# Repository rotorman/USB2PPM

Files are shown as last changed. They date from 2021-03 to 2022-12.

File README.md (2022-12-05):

# USB2PPM
Interface to control a remote device (e.g. a drone) from the PC via a radio link.

The USB2PPM circuit gets the signal from PC over USB connection and converts it to Pulse-Position-Modulation (PPM) to be input e.g. over a trainer jack into a remote control transmitter.

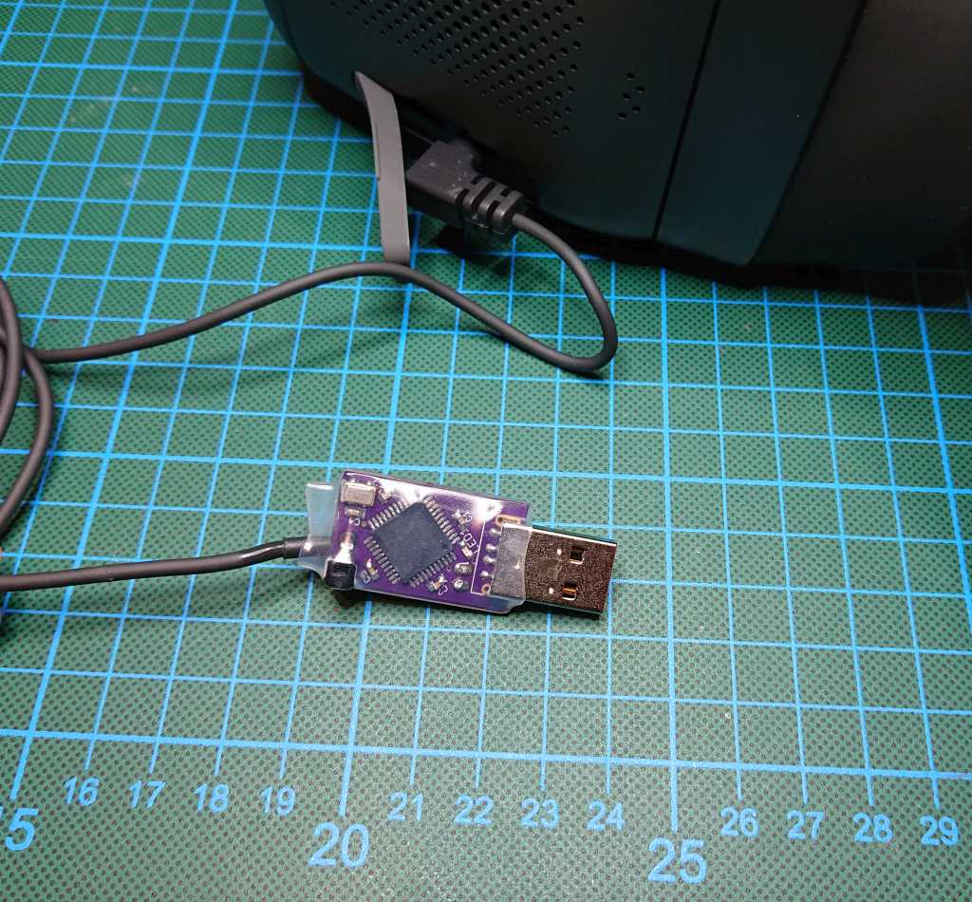
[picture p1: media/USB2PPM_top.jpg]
Top side of the PCB
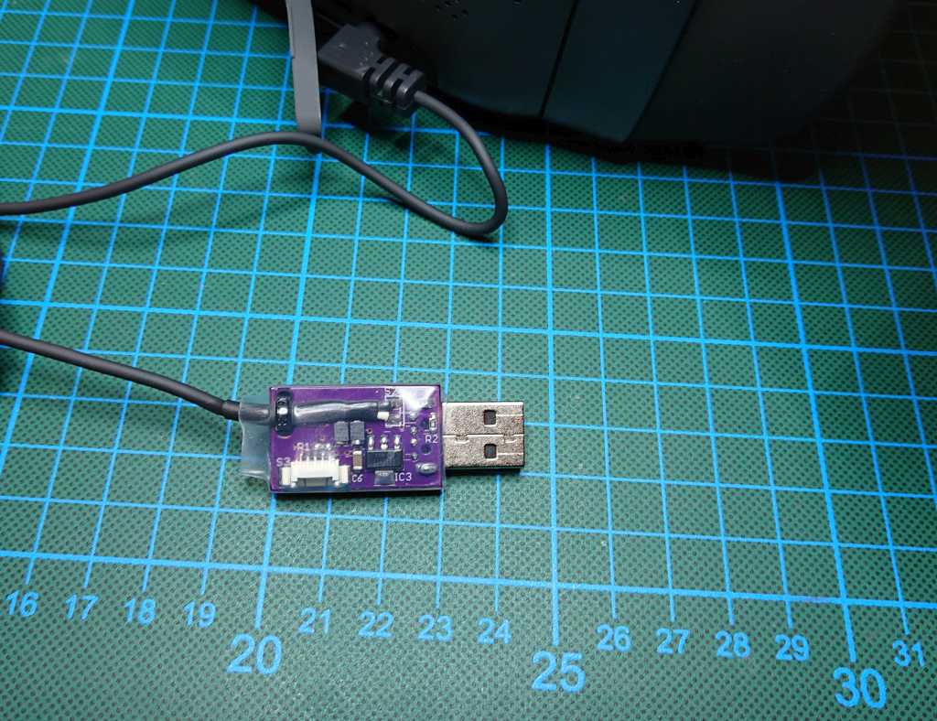
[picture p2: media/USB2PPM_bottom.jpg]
Bottom side of the PCB
 

USB2PPM outputs standard trainer port signal. You will find Eagle schematic & board files, Microchip MPLAB X PIC32 Harmony project (including pre-built firmware HEX) and two Microsoft Visual Studio .NET C# projects (incl. pre-built Windows binary) to control the board.

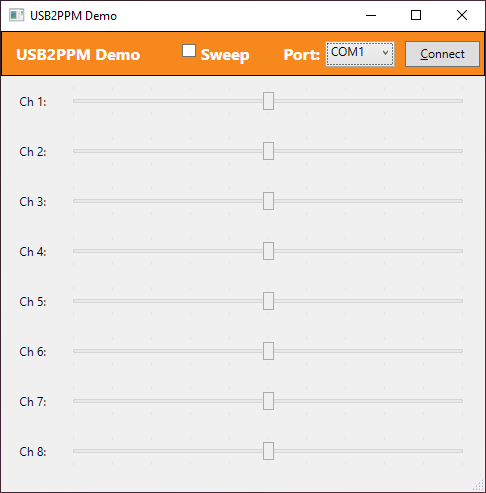
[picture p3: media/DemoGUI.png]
Demo GUI


USB2PPM circuit connects via USB-port of the PC and communicates over virtual serial port. Where the control input stems, depends only on the software running on the PC that transmits this info to the USB2PPM device.

### Communication protocol

The communication protocol is kept very simple. The connection with USB2PPM is with 115200 baud, 8N1. 

USB2PPM expects a constant 2 byte header (`0xF0 0xC4`) followed by eight uint16 values, sent MSB first (big-endian). Each of these uint16 values corresponds to a servo channel, starting with servo 1.

In the present firmware, the uint16 values code the servo channel pulse width in 200 ns resolution. The minimum accepted value is 1 ms (meaning value 5000 in decimal or `0x1388` in hex) and the maximum accepted value is 2 ms (meaning value 10000 or `0x2710` in hex).  Inputs outside the limits are capped to the borders of these limits (e.g., if you accidentally send 15000, the PIC32 firmware limits this input to 10000).

The USB2PPM echos the accepted input commands in human readable form (ASCII) back. There is no need to read, parse or acknowledge this feedback.

When sending the servo control telegram, you also do not need to adhere to any timing constraints or intervals when sending the data - after the telegram with new values has been accepted by USB2PPM, it continues to send out servo pulses with the commanded data until a new telegram with updated values is sent to it.

#### Examples

1) all 8 channels centered (1.5 ms)

`0xF0 0xC4  0x1D 0x4C 0x1D 0x4C 0x1D 0x4C 0x1D 0x4C 0x1D 0x4C 0x1D 0x4C 0x1D 0x4C 0x1D 0x4C`

2) all 8 channels minimum (1 ms):

`0xF0 0xC4 0x13 0x88 0x13 0x88 0x13 0x88 0x13 0x88 0x13 0x88 0x13 0x88 0x13 0x88 0x13 0x88`

3) all 8 channels maximum (2 ms):

`0xF0 0xC4 0x27 0x10 0x27 0x10 0x27 0x10 0x27 0x10 0x27 0x10 0x27 0x10 0x27 0x10 0x27 0x10`

4) channel 7 at 1.7 ms, rest at center:

`0xF0 0xC4  0x1D 0x4C 0x1D 0x4C 0x1D 0x4C 0x1D 0x4C 0x1D 0x4C 0x1D 0x4C 0x21 0x34 0x1D 0x4C`

(1.7 ms in 200 ns steps is 8500 that is in hex '0x2134'. The value 8500 stems from equation:

`pulse_width / step_size`

and here with example values for 1.7ms pulse width: 1.7 * 1000 * 1000 / 200 = 8500.

The first 1000 in the multiplication is to get from milliseconds to microseconds and the second multiplication with 1000 to get from microsecons to nanoseconds.

### Discussion

Project discussion in RC Groups forum blog post:

<https://www.rcgroups.com/forums/showthread.php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>

# S.BUS

The subfolder FTDI_SBUS has some examples of how to directly output a S.BUS signal from a computer, using e.g. a [FTDI adapter](https://www.sparkfun.com/products/9717) and an [inverter](https://oshwlab.com/feather/S_Bus_Inverter_R2-fWQK2kewO). The inverter can be skipped, if the receiving end expects inverted S.BUS (=non-inverted UART) signal anyhow, for example [RadioMaster TX16S](https://www.radiomasterrc.com/products/tx16s-mark-ii-radio-controller) AUX-ports, used as S.BUS trainer inputs.

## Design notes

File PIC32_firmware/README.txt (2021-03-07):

This is the firmware source for the USB to PPM (Pulse Position Modulation) converter.
 
Code for USB2PPM v1.0 PCB with PIC32MX270F256D.
PPM output is over pin 43 / RB7.
  
Uses Output Compare (OC1) together with Timer 3 module.
Pulse generation happens in OC1 ISR ("IntHandlerDrvOCInstance0()" in system_interrupt.c).
The unit replies input in human readable form (the generated pulse lengths).

USB CDC communication with host: 115200 8N1, no flow.
It uses the Microchip Harmony v2.06 CDC single driver, found under default installation:
C:\microchip\harmony\v2_06\apps\usb\device\cdc_com_port_single\inf
 
Protocol from host: F0 C4 <Servo1, uint16 MSB first> ... <Servo 8>
Servo data is in 0.2 µs ticks, thus middle position 1500 µs = 7500 = 0x1D4C
Limits are 1 ms (5000 = 0x1388) and 2 ms (10000 = 0x2710).
Inputs outside the limits are capped to the borders of the limits.
The system confirms the accepted input commands in human readable form
(output is a ASCII line of the generated pulse lengths).

This code is tested with Microchip MPLAB X v5.45, XC32 v2.50 and Harmony v2.06.

= Setting up the build environment =

For downloading and setting up the programming environment, please see:
1) https://www.microchip.com/mplab/mplab-x-ide
2) https://www.microchip.com/mplab/compilers
3) https://www.microchip.com/mplab/mplab-harmony/mplab-harmony-v2

Please check out the code to your harmony folder structure under
\third_party\own\apps\USB2PPM

As an example, under Windows, the MPLAB project would need to go under:
C:\microchip\harmony\v2_06\third_party\own\apps\USB2PPM\firmware

The code is making use of FreeRTOS extensions for multi-tasking and thread safe communication.
https://www.freertos.org/
https://www.freertos.org/wp-content/uploads/2018/07/161204_Mastering_the_FreeRTOS_Real_Time_Kernel-A_Hands-On_Tutorial_Guide.pdf

Please note that unfortunately there is an important bug in the FreeRTOS version, shipping
with Harmony v2.06, causing the sprintf() to fail (sprintf() is used in this firmware).
Please see Richard Barry, the author of FreeRTOS, explain the problem and how to remedy this:
https://www.freertos.org/FreeRTOS_Support_Forum_Archive/November_2010/freertos_Bad_sprintf_behaviour_on_PIC32_3951286.html
In short, you need to modify a single line in the function pxPortInitialiseStack() in file:
\third_party\rtos\FreeRTOS\Source\portable\MPLAB\PIC32MX\port.c
The first pxTopOfStack decrementor needs to decrement 2 counts, not only one, thus change it to:
pxTopOfStack-=2;

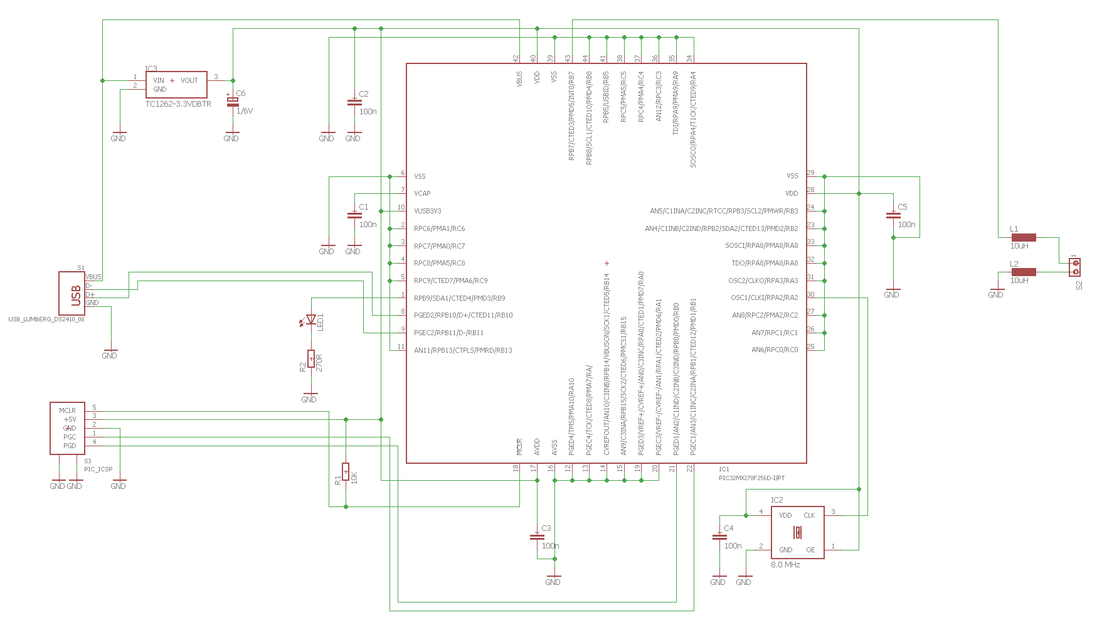
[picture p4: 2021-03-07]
SchematicAndBoard/USB2PPM_schematics.png

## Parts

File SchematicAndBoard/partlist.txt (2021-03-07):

C1-C5  100nF                 SMD 0805
C6     1µF 6V                SMC-A
IC1    PIC32MX270F256D-I/PT  TQFP44
IC2    8.0 MHz 3.3V Osc      DFN_3.2X5MM  EuroQuarz 8.000MHZ XO53050UITA
IC3    TC1262-3.3VDBTR       SOT223
L1-L2  10µH                  SMD 3225
LED1   green                 SMD 0805
R1     10K                   SMD 0805
R2     270R                  SMD 0805
S1     USB-A                 LUMBERG 53842
S2     3,5mm mono jack with cable
S3     ICSP header, Molex PicoBlade 53398-0571

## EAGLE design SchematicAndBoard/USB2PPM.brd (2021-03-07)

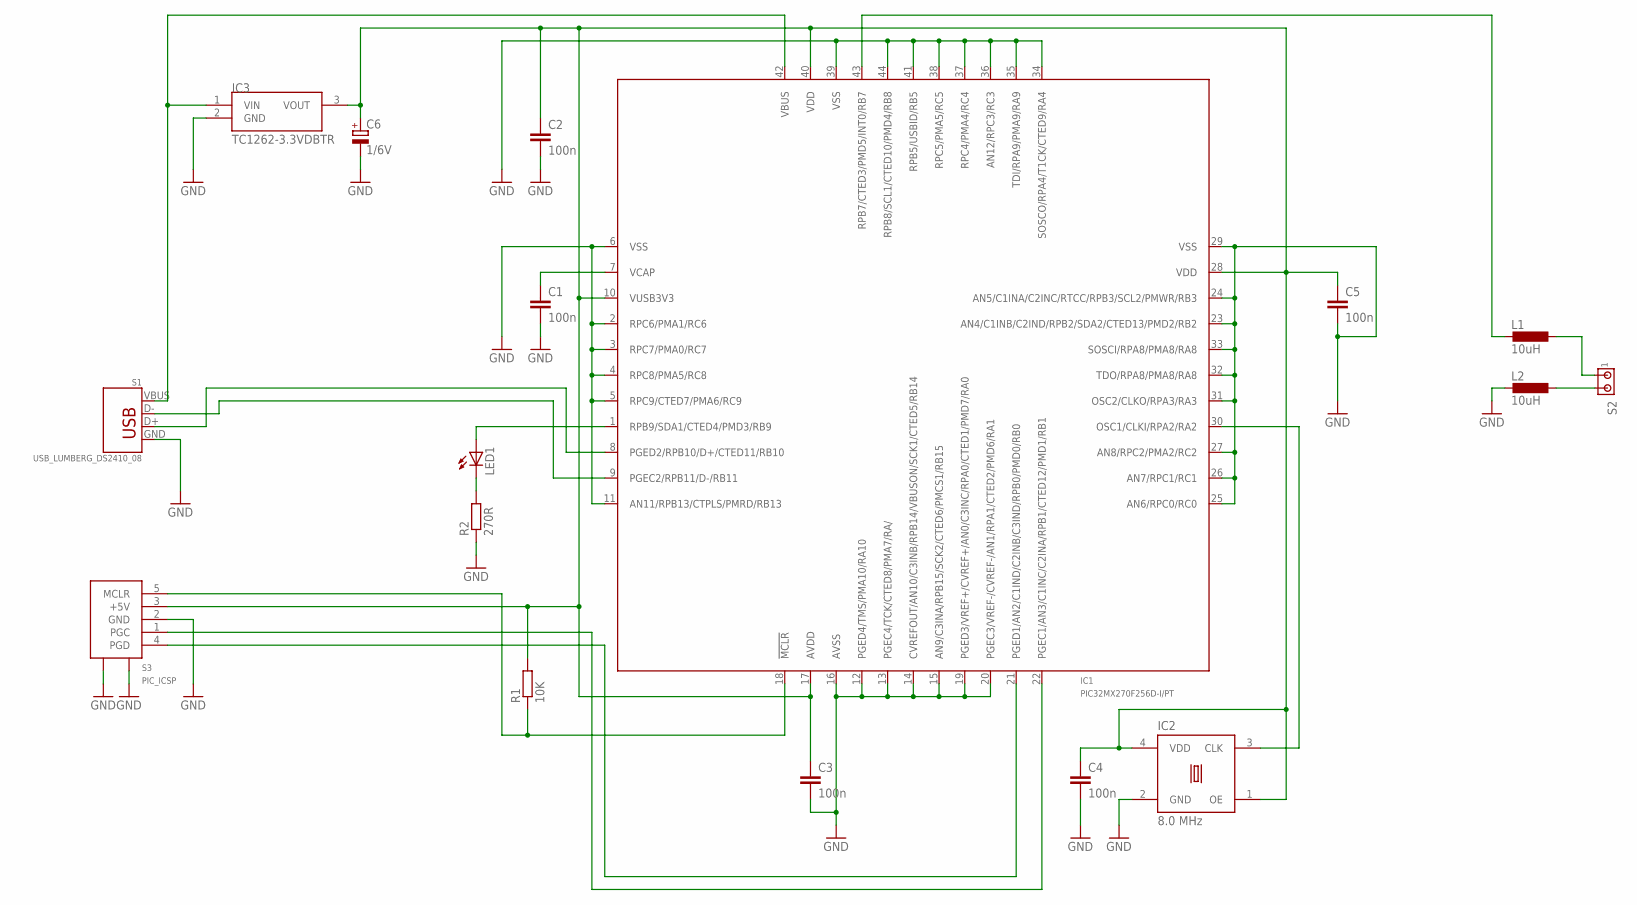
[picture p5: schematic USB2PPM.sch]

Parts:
C1, C2, C3, C4, C5: 100n; C0805K
C6: 1/6V; SMC_A
IC1: PIC32MX270F256D-I/PT; TQFP44
IC2: 8.0 MHz; DFN_3.2X5MM(4MM)
IC3: TC1262-3.3VDBTR; SOT223
L1, L2: 10uH; L3225M
LED1: LEDSML0805; SML0805
R1: 10K; R0805W
R2: 270R; R0805W
S1: USB_LUMBERG_DS2410_08; USB-A-LUMBERG_DS2410_08
S2: MTA02-100; 10X02MTA
S3: PIC_ICSP; 53395-05_GND

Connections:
!MCLR: IC1.18 (!MCLR), R1.1, S3.5 (MCLR)
+5V_USB: IC1.42 (VBUS), IC3.1 (VIN), S1.VBUS (GND)
D+: IC1.8 (PGED2/RPB10/D+/CTED11/RB10), S1.D+ (D-)
D-: IC1.9 (PGEC2/RPB11/D-/RB11), S1.D- (D+)
GND: C1.2, C2.2, C3.2, C4.2, C5.2, C6.-, IC1.2 (RPC6/PMA1/RC6), IC1.3 (RPC7/PMA0/RC7), IC1.4 (RPC8/PMA5/RC8), IC1.5 (RPC9/CTED7/PMA6/RC9), IC1.6 (VSS), IC1.11 (AN11/RPB13/CTPLS/PMRD/RB13), IC1.12 (PGED4/TMS/PMA10/RA10), IC1.13 (PGEC4/TCK/CTED8/PMA7/RA/), IC1.14 (CVREFOUT/AN10/C3INB/RPB14/VBUSON/SCK1/C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), IC1.15 (AN9/C3INA/RPB15/SCK2/CTED6/PMCS1/RB15), IC1.16 (AVSS), IC1.19 (PGED3/VREF+/CVREF+/AN0/C3INC/RPA0/CTED1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), IC1.20 (PGEC3/VREF-/CVREF-/AN1/RPA1/CTED2/PMD6/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), IC1.23 (AN4/C1INB/C2IND/RPB2/SDA2/CTED13/PMD2/R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), IC1.24 (AN5/C1INA/C2INC/RTCC/RPB3/SCL2/PMWR/RB3), IC1.25 (AN6/RPC0/RC0), IC1.26 (AN7/RPC1/RC1), IC1.27 (AN8/RPC2/PMA2/RC2), IC1.29 (VSS), IC1.31 (OSC2/CLKO/RPA3/RA3), IC1.32 (TDO/RPA8/PMA8/RA8), IC1.33 (SOSCI/RPA8/PMA8/RA8), IC1.34 (SOSCO/RPA4/T1CK/CTED9/RA4), IC1.35 (TDI/RPA9/PMA9/RA9), IC1.36 (AN12/RPC3/RC3), IC1.37 (RPC4/PMA4/RC4), IC1.38 (RPC5/PMA5/RC5), IC1.39 (VSS), IC1.41 (RPB5/USBID/RB5), IC1.44 (RPB8/SCL1/CTED10/PMD4/RB8), IC2.2 (GND), IC3.2 (GND), L2.2, R2.1, S1.GND (VBUS), S3.2 (GND), S3.S1 (GND), S3.S2 (GND)
LED: IC1.1 (RPB9/SDA1/CTED4/PMD3/RB9), LED1.A
unnamed: LED1.C, R2.2
OSC: IC1.30 (OSC1/CLKI/RPA2/RA2), IC2.3 (CLK)
PGC: IC1.22 (PGEC1/AN3/C1INC/C2INA/RPB1/CTED12/PMD1/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), S3.1 (PGC)
PGD: IC1.21 (PGED1/AN2/C1IND/C2INB/C3IND/RPB0/PMD0/R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), S3.4 (PGD)
PPM: IC1.43 (RPB7/CTED3/PMD5/INT0/RB7), L1.2
PPM_GND: L2.1, S2.2
PPM_OUT: L1.1, S2.1
VCAP: C1.1, IC1.7 (VCAP)
VDD: C2.1, C3.1, C4.1, C5.1, C6.+, IC1.10 (VUSB3V3), IC1.17 (AVDD), IC1.28 (VDD), IC1.40 (VDD), IC2.1 (OE), IC2.4 (VDD), IC3.3 (VOUT), R1.2, S3.3 (+5V)

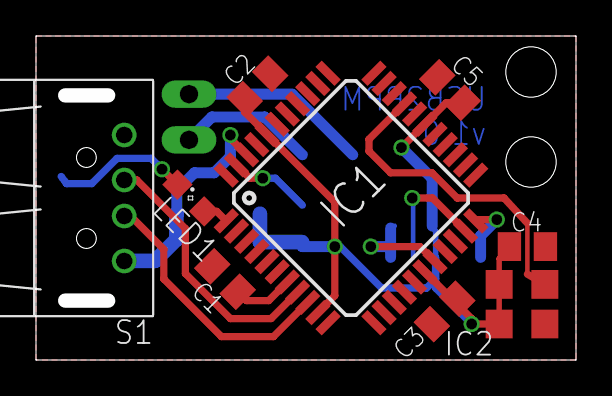
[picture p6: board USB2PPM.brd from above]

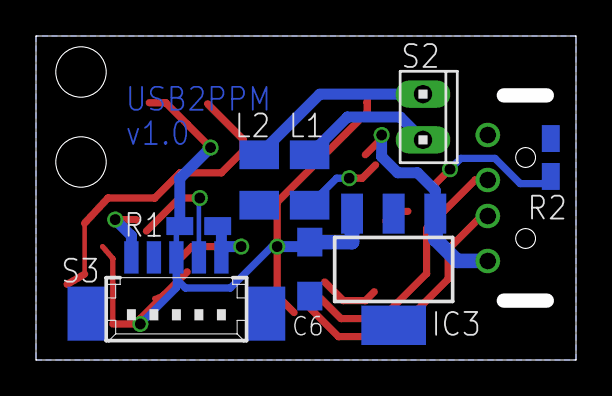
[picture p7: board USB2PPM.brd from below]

Board: 2 copper layers, 30.0 x 18.0 mm, 17 parts (8 on the bottom side), 15 nets.

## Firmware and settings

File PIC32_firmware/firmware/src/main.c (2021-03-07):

/*******************************************************************************
  MPLAB Harmony Project Main Source File

  Company:
    Microchip Technology Inc.
  
  File Name:
    main.c

  Summary:
    This file contains the "main" function for an MPLAB Harmony project.

  Description:
    This file contains the "main" function for an MPLAB Harmony project.  The
    "main" function calls the "SYS_Initialize" function to initialize the state 
    machines of all MPLAB Harmony modules in the system and it calls the 
    "SYS_Tasks" function from within a system-wide "super" loop to maintain 
    their correct operation. These two functions are implemented in 
    configuration-specific files (usually "system_init.c" and "system_tasks.c")
    in a configuration-specific folder under the "src/system_config" folder 
    within this project's top-level folder.  An MPLAB Harmony project may have
    more than one configuration, each contained within it's own folder under
    the "system_config" folder.
 *******************************************************************************/

// DOM-IGNORE-BEGIN
/*******************************************************************************
Copyright (c) 2013-2014 released Microchip Technology Inc.  All rights reserved.

//Microchip licenses to you the right to use, modify, copy and distribute
Software only when embedded on a Microchip microcontroller or digital signal
controller that is integrated into your product or third party product
(pursuant to the sublicense terms in the accompanying license agreement).

You should refer to the license agreement accompanying this Software for
additional information regarding your rights and obligations.

SOFTWARE AND DOCUMENTATION ARE PROVIDED "AS IS" WITHOUT WARRANTY OF ANY KIND,
EITHER EXPRESS OR IMPLIED, INCLUDING WITHOUT LIMITATION, ANY WARRANTY OF
MERCHANTABILITY, TITLE, NON-INFRINGEMENT AND FITNESS FOR A PARTICULAR PURPOSE.
IN NO EVENT SHALL MICROCHIP OR ITS LICENSORS BE LIABLE OR OBLIGATED UNDER
CONTRACT, NEGLIGENCE, STRICT LIABILITY, CONTRIBUTION, BREACH OF WARRANTY, OR
OTHER LEGAL EQUITABLE THEORY ANY DIRECT OR INDIRECT DAMAGES OR EXPENSES
INCLUDING BUT NOT LIMITED TO ANY INCIDENTAL, SPECIAL, INDIRECT, PUNITIVE OR
CONSEQUENTIAL DAMAGES, LOST PROFITS OR LOST DATA, COST OF PROCUREMENT OF
SUBSTITUTE GOODS, TECHNOLOGY, SERVICES, OR ANY CLAIMS BY THIRD PARTIES
(INCLUDING BUT NOT LIMITED TO ANY DEFENSE THEREOF), OR OTHER SIMILAR COSTS.
 *******************************************************************************/
// DOM-IGNORE-END


// *****************************************************************************
// *****************************************************************************
// Section: Included Files
// *****************************************************************************
// *****************************************************************************

#include <stddef.h>                     // Defines NULL
#include <stdbool.h>                    // Defines true
#include <stdlib.h>                     // Defines EXIT_FAILURE
#include "system/common/sys_module.h"   // SYS function prototypes


// *****************************************************************************
// *****************************************************************************
// Section: Main Entry Point
// *****************************************************************************
// *****************************************************************************

int main ( void )
{
    /* Initialize all MPLAB Harmony modules, including application(s). */
    SYS_Initialize ( NULL );

    while ( true )
    {
        /* Maintain state machines of all polled MPLAB Harmony modules. */
        SYS_Tasks ( );

    }

    /* Execution should not come here during normal operation */

    return ( EXIT_FAILURE );
}



/*-----------------------------------------------------------*/



/*******************************************************************************
 End of File
*/

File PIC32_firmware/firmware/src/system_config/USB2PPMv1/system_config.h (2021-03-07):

/*******************************************************************************
  MPLAB Harmony System Configuration Header

  File Name:
    system_config.h

  Summary:
    Build-time configuration header for the system defined by this MPLAB Harmony
    project.

  Description:
    An MPLAB Project may have multiple configurations.  This file defines the
    build-time options for a single configuration.

  Remarks:
    This configuration header must not define any prototypes or data
    definitions (or include any files that do).  It only provides macro
    definitions for build-time configuration options that are not instantiated
    until used by another MPLAB Harmony module or application.

    Created with MPLAB Harmony Version 2.06
*******************************************************************************/

// DOM-IGNORE-BEGIN
/*******************************************************************************
Copyright (c) 2013-2015 released Microchip Technology Inc.  All rights reserved.

Microchip licenses to you the right to use, modify, copy and distribute
Software only when embedded on a Microchip microcontroller or digital signal
controller that is integrated into your product or third party product
(pursuant to the sublicense terms in the accompanying license agreement).

You should refer to the license agreement accompanying this Software for
additional information regarding your rights and obligations.

SOFTWARE AND DOCUMENTATION ARE PROVIDED AS IS WITHOUT WARRANTY OF ANY KIND,
EITHER EXPRESS OR IMPLIED, INCLUDING WITHOUT LIMITATION, ANY WARRANTY OF
MERCHANTABILITY, TITLE, NON-INFRINGEMENT AND FITNESS FOR A PARTICULAR PURPOSE.
IN NO EVENT SHALL MICROCHIP OR ITS LICENSORS BE LIABLE OR OBLIGATED UNDER
CONTRACT, NEGLIGENCE, STRICT LIABILITY, CONTRIBUTION, BREACH OF WARRANTY, OR
OTHER LEGAL EQUITABLE THEORY ANY DIRECT OR INDIRECT DAMAGES OR EXPENSES
INCLUDING BUT NOT LIMITED TO ANY INCIDENTAL, SPECIAL, INDIRECT, PUNITIVE OR
CONSEQUENTIAL DAMAGES, LOST PROFITS OR LOST DATA, COST OF PROCUREMENT OF
SUBSTITUTE GOODS, TECHNOLOGY, SERVICES, OR ANY CLAIMS BY THIRD PARTIES
(INCLUDING BUT NOT LIMITED TO ANY DEFENSE THEREOF), OR OTHER SIMILAR COSTS.
*******************************************************************************/
// DOM-IGNORE-END

#ifndef _SYSTEM_CONFIG_H
#define _SYSTEM_CONFIG_H

// *****************************************************************************
// *****************************************************************************
// Section: Included Files
// *****************************************************************************
// *****************************************************************************
/*  This section Includes other configuration headers necessary to completely
    define this configuration.
*/


// DOM-IGNORE-BEGIN
#ifdef __cplusplus  // Provide C++ Compatibility

extern "C" {

#endif
// DOM-IGNORE-END

// *****************************************************************************
// *****************************************************************************
// Section: System Service Configuration
// *****************************************************************************
// *****************************************************************************
// *****************************************************************************
/* Common System Service Configuration Options
*/
#define SYS_VERSION_STR           "2.06"
#define SYS_VERSION               20600

// *****************************************************************************
/* Clock System Service Configuration Options
*/
#define SYS_CLK_FREQ                        40000000ul
#define SYS_CLK_BUS_PERIPHERAL_1            40000000ul
#define SYS_CLK_UPLL_BEFORE_DIV2_FREQ       96000000ul
#define SYS_CLK_CONFIG_PRIMARY_XTAL         8000000ul
#define SYS_CLK_CONFIG_SECONDARY_XTAL       32768ul
   
/*** Ports System Service Configuration ***/
#define SYS_PORT_A_ANSEL        0xF864      // xxxx xDDD DxxD DADD
#define SYS_PORT_A_TRIS         0xFFFF      // OK
#define SYS_PORT_A_LAT          0x0000
#define SYS_PORT_A_ODC          0x0000
#define SYS_PORT_A_CNPU         0x0000
#define SYS_PORT_A_CNPD         0x0000
#define SYS_PORT_A_CNEN         0x0000

#define SYS_PORT_B_ANSEL        0x1C43      // DDDx AADD DxDD DDAA
#define SYS_PORT_B_TRIS         0xFD7F      // IIIx IIOI OxII IIII
#define SYS_PORT_B_LAT          0x0000
#define SYS_PORT_B_ODC          0x0000
#define SYS_PORT_B_CNPU         0x0000
#define SYS_PORT_B_CNPD         0x0000
#define SYS_PORT_B_CNEN         0x0000

#define SYS_PORT_C_ANSEL        0xFC00      // xxxx xxDD DDDD DDDD
#define SYS_PORT_C_TRIS         0xFFFF      // OK
#define SYS_PORT_C_LAT          0x0000
#define SYS_PORT_C_ODC          0x0000
#define SYS_PORT_C_CNPU         0x0000
#define SYS_PORT_C_CNPD         0x0000
#define SYS_PORT_C_CNEN         0x0000

/*** Interrupt System Service Configuration ***/
#define SYS_INT                     true
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

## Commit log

2021-03-07 Initial state
    [USB2PPM.brd, USB2PPM.sch]
2022-12-03 Added steering wheel demo
2022-12-03 Moved to FTDI_SBUS subfolder. Added ch4 and ch5 as mixed throttle and brake channels, where ch5 is brake priority mode mix.
